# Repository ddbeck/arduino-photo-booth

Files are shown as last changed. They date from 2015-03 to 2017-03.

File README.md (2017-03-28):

# Arduino Photo Booth

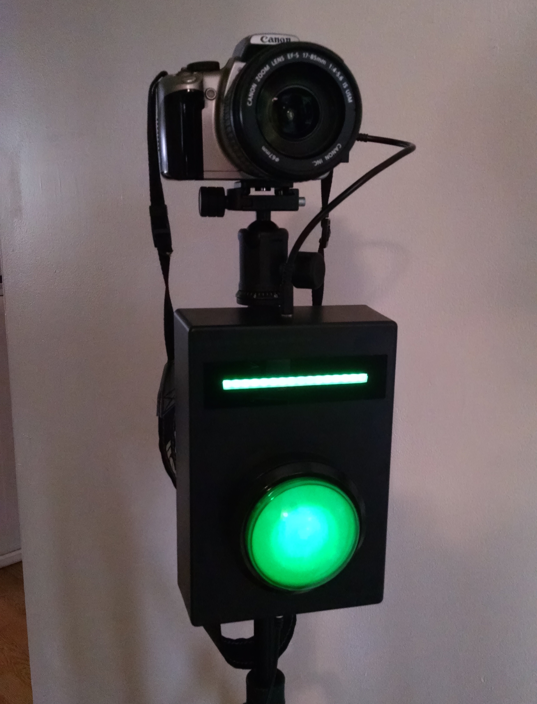
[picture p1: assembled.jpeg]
a photo of the components in an enclosure


This repository contains the source for a photo booth driven by an Arduino-based intervalometer connected to a Canon EOS 350D camera. I put together this project for my friends' wedding reception in March 2015, in lieu of them renting a hugely expensive photo booth from a vendor. Instead of using a photo printer, I used [an eyefi Wi-Fi SD card](http://www.eyefi.com/) to automatically upload photos to flickr, so photo booth users could see their work on their smartphones soon after taking a photo. The reception attendees had a great time with it: [see for yourself](https://www.flickr.com/gp/52758581@N00/L60397)!

Here's an illustration of the circuit:

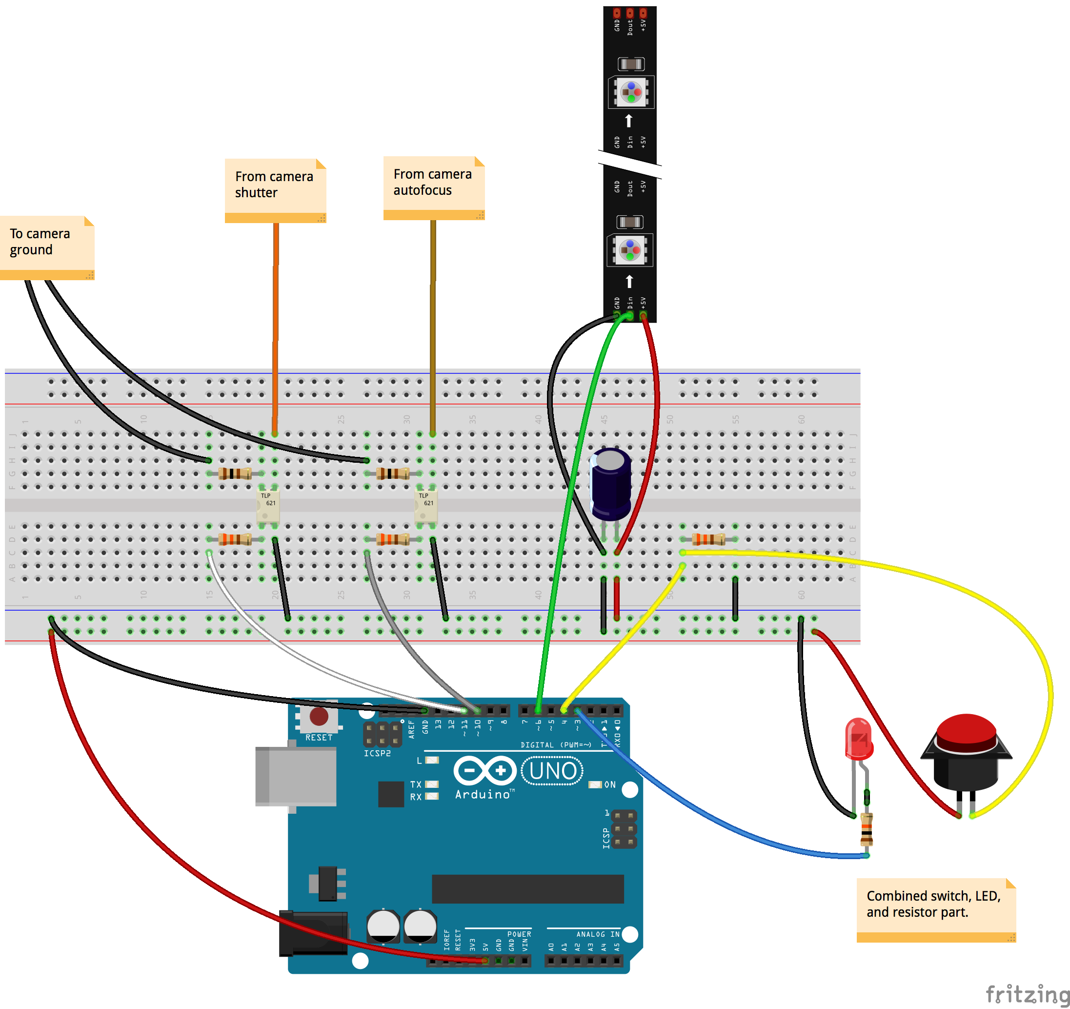
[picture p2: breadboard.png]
a Fritzing illustration of the circuit on a breadboard


And here's the circuit as assembled on a prototyping board:

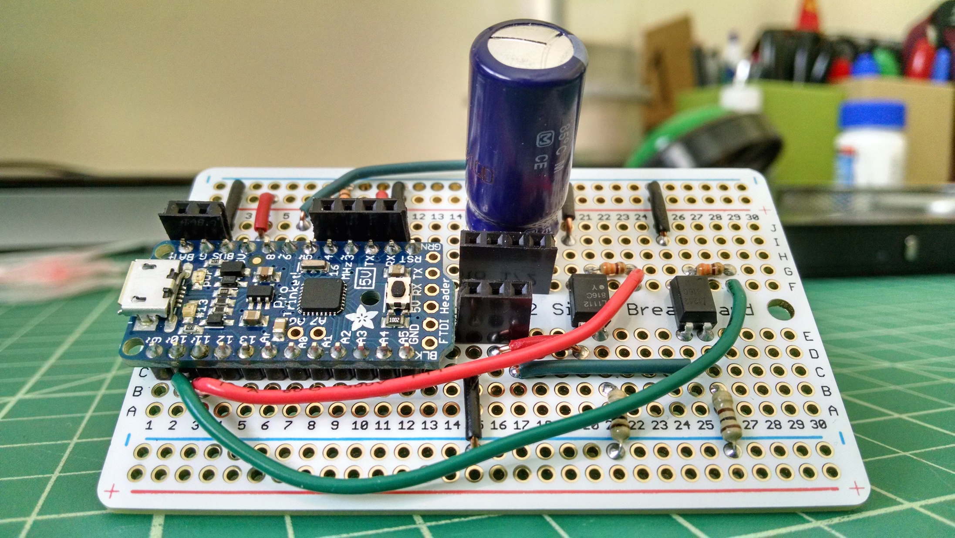
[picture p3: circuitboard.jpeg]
a photo of the assembled circuit


# Dependencies

This project assumes the following hardware components:

Pin | Component
--- | ---------
3   | LED
4   | [Arcade button microswitch](http://www.adafruit.com/products/1188), normally open
6   | Two chained [Adafruit NeoPixel Sticks](http://www.adafruit.com/products/1426)
10  | A single-channel [optoisolator](https://www.sparkfun.com/products/314) (autofocus)
11  | A single-channel optoisolator (shutter)

Digital pin 13 is also used for controlling the built-in surface mount LED on the Arduino Uno. The LED is used for debugging purposes, and is not required for normal operation.

The sketch requires the following libraries:

* [Adafruit NeoPixel Arduino library](https://learn.adafruit.com/adafruit-neopixel-uberguide/arduino-library)
* [Andy Brown's Arduino easing library](http://andybrown.me.uk/wk/2010/12/05/animation-on-the-arduino-with-easing-functions/)

# Usage

Upload the sketch to your Arduino Uno or compatible micro controller (see [the official Arduino IDE documentation](http://arduino.cc/en/Guide/HomePage) for detailed instructions).

# License

This project is MIT licensed. See the included `LICENSE` file for details.

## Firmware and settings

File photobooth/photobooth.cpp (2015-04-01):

// =========
// Debugging
// =========
#define DEBUG


// =====================
// Headers and Libraries
// =====================
#include <Arduino.h>
#include <Adafruit_NeoPixel.h>
#include <EasingLibrary.h>
#include "debug.h"


// ========
// Settings
// ========

// --- Pins ---
// Trinket Pro pins off-limits: 2, 7
const int SMD_LED_PIN = 13;
const int BUTTON_LED_PIN = 3;
const int BUTTON_PIN = 4;
const int NEOPIXEL_PIN = 6;
const int AUTOFOCUS_PIN = 10;  // Red wire
const int SHUTTER_PIN = 11;  // Yellow wire


// ========
// NeoPixel
// ========
const int NEOPIXEL_LENGTH = 16;
Adafruit_NeoPixel strip = Adafruit_NeoPixel(NEOPIXEL_LENGTH,
                                            NEOPIXEL_PIN,
                                            NEO_GRB + NEO_KHZ800);

// --- Colors ---
const uint32_t GREEN = strip.Color(0, 18, 0);
const uint32_t YELLOW = strip.Color(18, 18, 0);
const uint32_t RED = strip.Color(18, 0, 0);
const uint32_t WHITE = strip.Color(18, 18, 18);
const uint32_t FLASH = strip.Color(255, 255, 255);
const uint32_t OFF = strip.Color(0, 0, 0);


// =======
// Support
// =======
void lightLED(bool on, int pin, String name){
    // Turn on or off an LED.
    if (on) {
        digitalWrite(pin, HIGH);
        debugPrint(name + " LED on.");
    }
    else {
        digitalWrite(pin, LOW);
        debugPrint(name + " LED off.");
    }
}


void lightButton(bool on) {
    lightLED(on, BUTTON_LED_PIN, "Arcade button");
}


void lightButton(int brightness) {
    analogWrite(BUTTON_LED_PIN, brightness);
}


void lightSMD(bool on) {
    lightLED(on, SMD_LED_PIN, "SMD");
}


void setStrip(uint32_t color) {
    for(int i = 0; i < strip.numPixels(); i++) {
        strip.setPixelColor(i, color);
    }
    strip.show();
}


bool isButtonPressed() {
    bool firstRead = digitalRead(BUTTON_PIN) == HIGH ? true : false;
    delay(5);
    bool secondRead = digitalRead(BUTTON_PIN) == HIGH ? true : false;

    if (firstRead && secondRead) {
        debugPrint("Button depressed.");
    }

    return firstRead && secondRead;
}


void autofocus(bool on) {
    digitalWrite(AUTOFOCUS_PIN, on ? HIGH : LOW);
}


void shutter(bool on) {
    digitalWrite(SHUTTER_PIN, on ? HIGH : LOW);
}


// ======================
// Lights, Camera, Action
// ======================
typedef struct CountdownState {
    int duration;
    int pixels;
    uint32_t color;
    String command;
} CountdownState;

CountdownState countdownStates[10] = {
    {750, 16, GREEN},
    {750, 14, GREEN},
    {750, 12, GREEN},
    {750, 10, YELLOW},
    {750, 8, YELLOW},
    {750, 6, YELLOW, "AUTOFOCUS_ON"},
    {750, 4, RED},
    {750, 2, RED},
    {10, 16, FLASH, "SHUTTER_ON"},
    {10, 16, OFF, "ALL_OFF"},
};


void setCountdownState(CountdownState state) {
    int pixelCount = strip.numPixels();

    int offset = (pixelCount - state.pixels) / 2;
    int startIndex = 0 + offset;
    int endIndex = pixelCount - 1 - offset;

    debugPrint(String("Setting pixels [") + startIndex + String(",") +
               endIndex + String("] to ") + state.color);
    for (int pixelIndex = 0; pixelIndex < strip.numPixels(); pixelIndex++) {
        bool inRange = (pixelIndex >= startIndex) && (pixelIndex <= endIndex);

        if (inRange) {
            strip.setPixelColor(pixelIndex, state.color);
        }
        else {
            strip.setPixelColor(pixelIndex, OFF);
        }
    }
    strip.show();
    debugPrint("Finished setting pixels.");
}


// ==============
// Intervalometer
// ==============


void controlCamera(String command) {
    if (String("AUTOFOCUS_ON") == command) {
        autofocus(true);
    }
    else if (String("AUTOFOCUS_OFF") == command) {
        autofocus(false);
    }
    else if (String("SHUTTER_ON") == command) {
        shutter(true);
    }
    else if (String("SHUTTER_OFF") == command) {
        shutter(false);
    }
    else if (String("ALL_OFF") == command) {
        shutter(false);
        autofocus(false);
    }
    else {
        debugPrint("ERROR: unrecognized camera command.");
    }
}


void countdown() {
    debugPrint("Starting countdown.");

    int countdownStep = 0;
    int stepStartTime = millis();
    int readTime = stepStartTime;

    while (countdownStep < sizeof(countdownStates) / sizeof(CountdownState)) {
        debugPrint(String("Animating index ") + countdownStep);

        setCountdownState(countdownStates[countdownStep]);
        stepStartTime = millis();

        controlCamera(countdownStates[countdownStep].command);

        while (true) {
            readTime = millis();
            if (readTime - stepStartTime >= countdownStates[countdownStep].duration) {
                debugPrint(String("Finished index ") + countdownStep +
                    String(" after ") + (readTime - stepStartTime) +
                    String("ms."));
                countdownStep++;
                break;
            }
        }
    }
    debugPrint("Exiting countdown.");
}


void standby() {
    debugPrint("Starting standby.");
    lightButton(true);
    setStrip(GREEN);

    const int maxButtonBrightness = 255;
    const int maxStripBrightness = 30;

    int duration = 1500;
    int startTime = millis();
    int lastTimeButton = startTime;
    SineEase ease;

    // The duration is half of the cycle (e.g., dark to light), so the full
    // cycle (e.g. dark to light to dark again) takes twice as long.
    ease.setDuration(duration); // half cycle in milliseconds

    // The total change in position controls the maximum brightness of the
    // NeoPixels. Because the NeoPixels have a range of 255 to 0, a total
    // change in position less than about 1/3rd the total brightness makes the
    // stops between values obvious as a sort of stutter in the animation.
    ease.setTotalChangeInPosition(1.0);

    double easedPosition;

    while (true) {
        if (millis() - lastTimeButton > 10) { // min change frequency is 10ms
            lastTimeButton = millis();
            easedPosition = ease.easeInOut((double)(lastTimeButton - startTime));
            lightButton((int)(easedPosition * maxButtonBrightness));

            if (lastTimeButton - startTime >= duration * 2) {
                startTime = millis();
            }
        }

        if (isButtonPressed()) {
            lightButton(false);
            setStrip(OFF);
            debugPrint("Exiting standby.");
            return;
        }
    }
}


// =======
// Arduino
// =======
void setup() {
    #ifdef DEBUG
        Serial.begin(9600);
        pinMode(SMD_LED_PIN, OUTPUT);
    #endif

    // Pin modes
    pinMode(BUTTON_LED_PIN, OUTPUT);
    pinMode(BUTTON_PIN, INPUT);
    pinMode(AUTOFOCUS_PIN, OUTPUT);
    pinMode(SHUTTER_PIN, OUTPUT);

    // LED states
    lightButton(true);
    lightSMD(true);

    // Neopixel
    strip.begin();
    strip.show();
}


void loop() {
    standby();
    countdown();
}

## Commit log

2015-01-30 add initial button blinker
2015-02-03 add a nicer api for toggling LEDs
2015-02-05 add button reading helper
2015-02-06 fix types in button reading function
    [photobooth.cpp]
2015-02-06 add missing pin and LED setup
    [photobooth.cpp]
2015-02-06 use easier routine for testing button function
2015-02-06 update readme for actual pin usage
2015-02-12 be less sensitive about button bounces
2015-02-13 turn on button light when entering standby
2015-02-13 add pulsing to button LED
2015-02-14 update component pin list in readme
2015-02-14 revised readme, added info on pin 13 usage
2015-02-15 add friendlier API for PWMing the button LED
2015-02-15 add camera control to countdown loop
2015-02-17 document camera wire colors
2015-03-02 add missing ground jumpers to illustration
2015-03-02 add breadboard illustration Fritzing file
    [breadboard.fzz]
2015-03-02 move button pin
    [breadboard.fzz]
2015-03-12 add circuit photo to readme
2015-03-24 add photo of enclosure
